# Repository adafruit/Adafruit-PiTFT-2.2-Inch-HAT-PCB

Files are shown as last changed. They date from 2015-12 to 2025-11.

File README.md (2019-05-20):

## Adafruit PiTFT 2.2 Inch LCD Display HAT
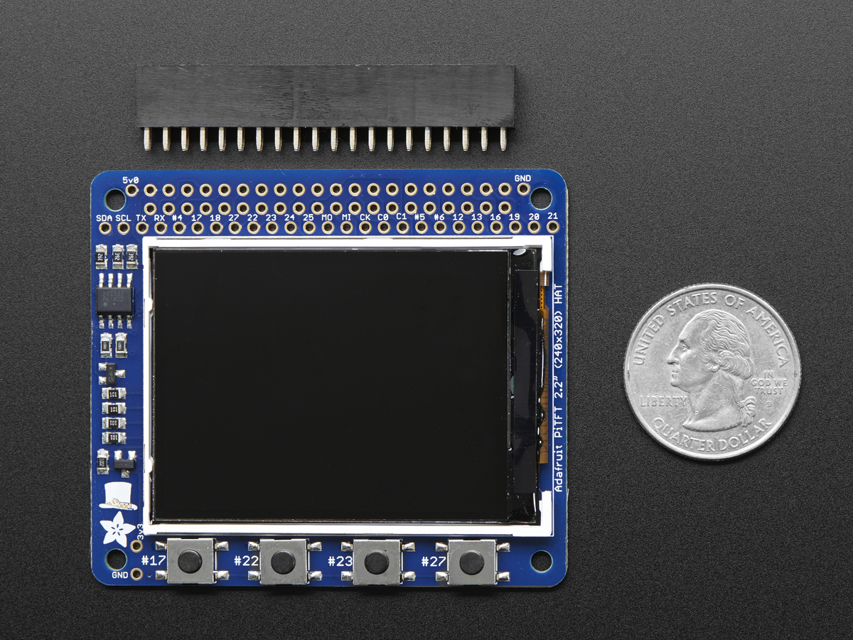
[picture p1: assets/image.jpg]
<a href="http://www.adafruit.com/products/2315"><br/>
Click here to purchase one from the Adafruit shop</a>

The cute PiTFT got even more adorable with this little primary display for Raspberry Pi in HAT form! It features a 2.2" display with 320x240 16-bit color pixels. The HAT uses the high speed SPI interface on the Pi and can use the mini display as a console, X window port, displaying images or video etc. Best of all it plugs right in on top of your Model A+ or B+ and fits into our case quite nicely.

It's designed to plug directly onto the Raspberry Pi 2, Pi 3, Pi Zero or Raspberry Pi 1 Model A+ or B+ . While not specifically designed for Pi Model A or B, you can use it with A/B if you solder in an extra-tall 2x13 header (not included) instead of the included 2x20 header

This design uses the hardware SPI pins (SCK, MOSI, MISO, CE0, CE1) as well as GPIO #25. All other GPIO are unused and are available on a 25-pin long breakout line. Since we had a tiny bit of space, there's 4 flat tactile switches wired to four GPIOs, that you can use if you want to make a basic user interface. For example, you can use one as a power on/off button.

Comes as a fully assembled display PCB and an additional 2x20 GPIO header. Some light soldering is required to attach the 2x20 GPIO header to the HAT but it's fast and easy for anyone with a soldering iron and solder.

PCB files for Adafruit PiTFT 2.2" HAT. The format is EagleCAD schematic and board layout
- https://www.adafruit.com/product/2315

### License

Adafruit invests time and resources providing this open source design, please support Adafruit and open-source hardware by purchasing products from [Adafruit](https://www.adafruit.com)!

All text above must be included in any redistribution

Designed by Limor Fried/Ladyada for Adafruit Industries.
Creative Commons Attribution/Share-Alike, all text above must be included in any redistribution. 
See license.txt for additional information.

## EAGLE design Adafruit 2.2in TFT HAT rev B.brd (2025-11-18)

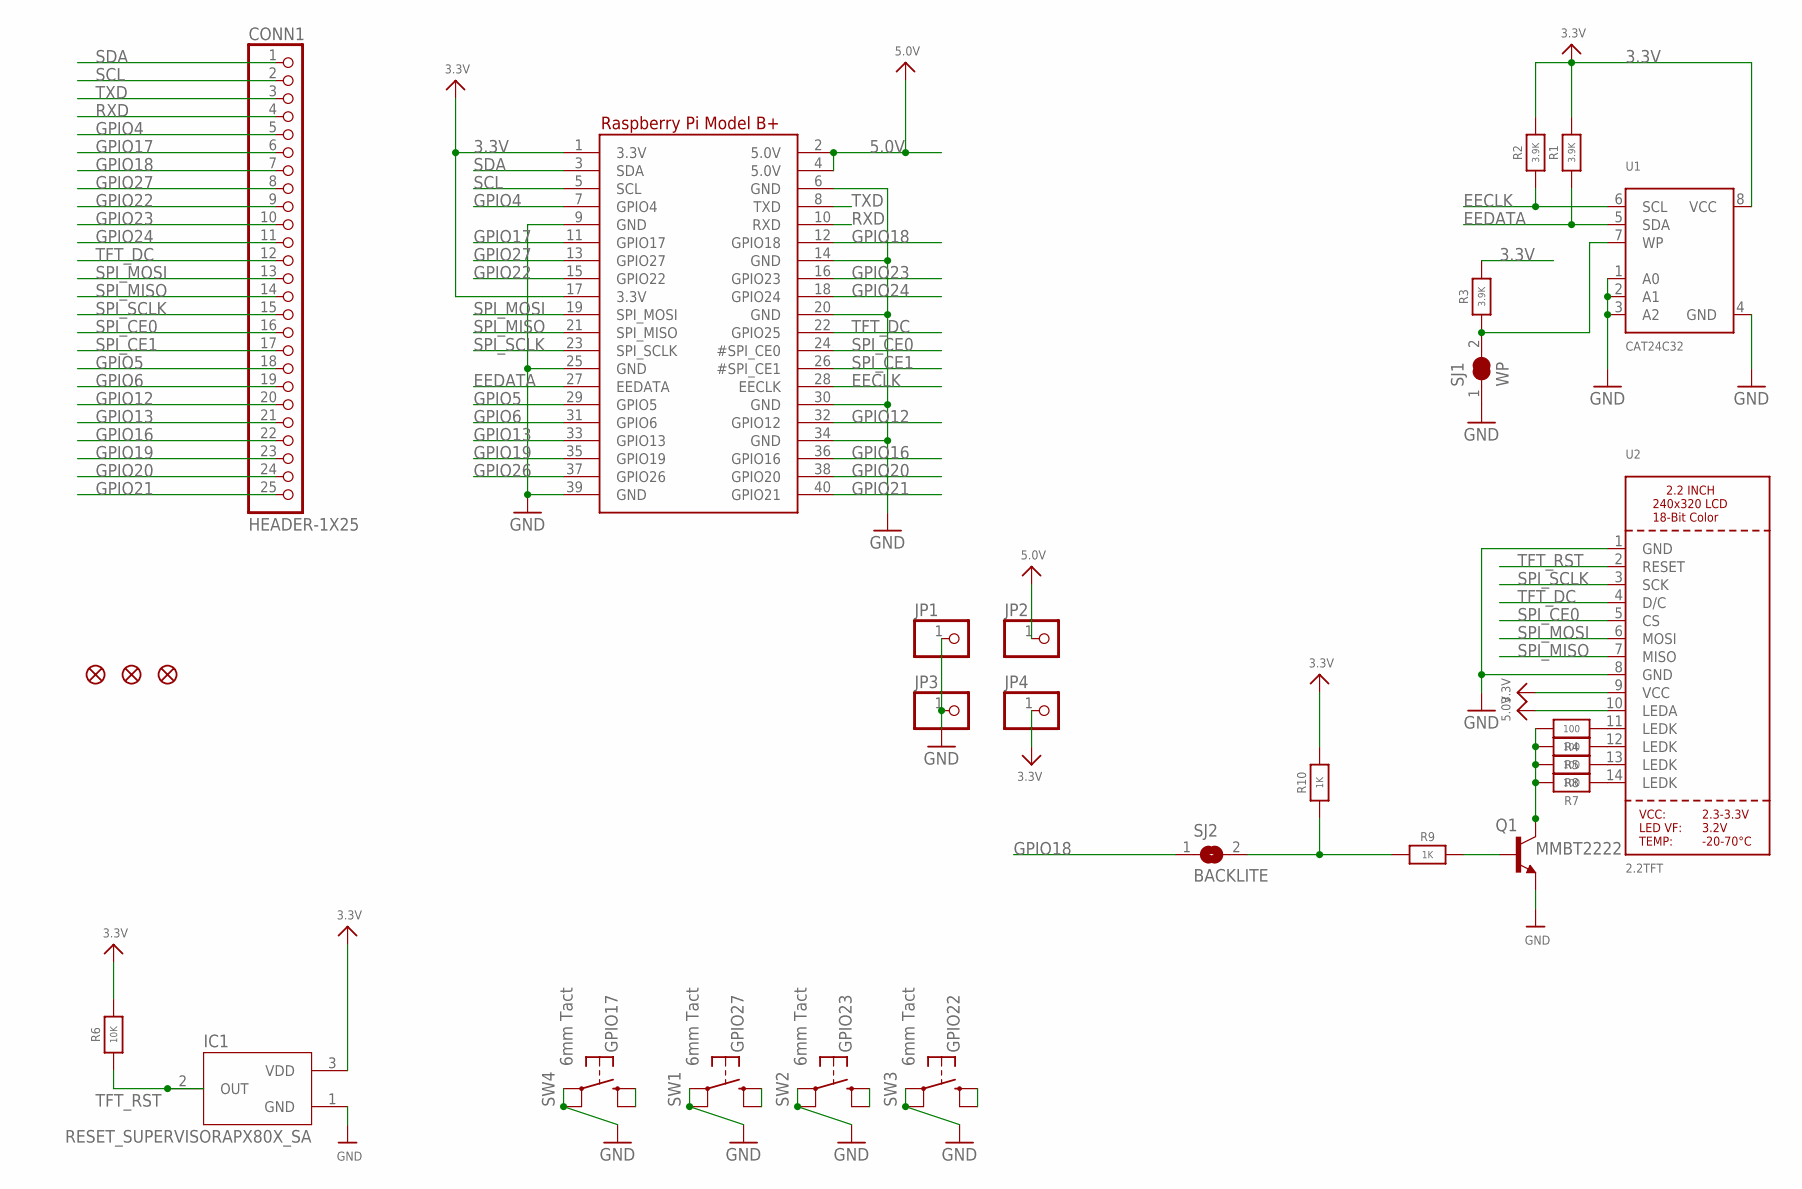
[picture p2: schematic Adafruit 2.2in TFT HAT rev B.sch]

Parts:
CONN1: HEADER-1X25; 1X25_ROUND_70MIL
FID1, FID2, FID3: FIDUCIAL_1MM
IC1: RESET_SUPERVISORAPX80X_SA; SOT23-WIDE
JP1, JP2, JP3, JP4: HEADER-1X1ROUND; 1X01_ROUND
Q1: MMBT2222; SOT23-BEC
R1, R2, R3: 3.9K; 0805-NO
R4, R5, R7, R8: 100; 0805-NO
R6: 10K; 0805-NO
R9, R10: 1K; 0805-NO
RPI1: RASPBERRYPI_BPLUS_HATNODIM; PI_HAT_NODIM
SJ1: WP; SOLDERJUMPER_CLOSEDWIRE
SJ2: BACKLITE; SOLDERJUMPER_CLOSEDWIRE
SW1, SW2, SW3, SW4: 6mm Tact; EVQ-Q2
U1: CAT24C32; SOIC8_150MIL
U2: 2.2TFT; TM022HDH26_2.2IN_LCD

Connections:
3.3V: IC1.3 (VDD), JP4.1, R1.2, R2.2, R3.2, R6.2, R10.2, RPI1.1 (3.3V), RPI1.17 (3.3V), U1.8 (VCC), U2.9 (VCC)
5.0V: JP2.1, RPI1.2 (5.0V), RPI1.4 (5.0V), U2.10 (LEDA)
EECLK: R2.1, RPI1.28 (EECLK), U1.6 (SCL)
EEDATA: R1.1, RPI1.27 (EEDATA), U1.5 (SDA)
GND: IC1.1 (GND), JP1.1, JP3.1, Q1.E, RPI1.6 (GND), RPI1.9 (GND), RPI1.14 (GND), RPI1.20 (GND), RPI1.25 (GND), RPI1.30 (GND), RPI1.34 (GND), RPI1.39 (GND), SJ1.1, SW1.A, SW1.A' (P1), SW2.A, SW2.A' (P1), SW3.A, SW3.A' (P1), SW4.A, SW4.A' (P1), U1.1 (A0), U1.2 (A1), U1.3 (A2), U1.4 (GND), U2.1 (GND), U2.8 (GND)
GPIO4: CONN1.5, RPI1.7 (GPIO4)
GPIO5: CONN1.18, RPI1.29 (GPIO5)
GPIO6: CONN1.19, RPI1.31 (GPIO6)
GPIO12: CONN1.20, RPI1.32 (GPIO12)
GPIO13: CONN1.21, RPI1.33 (GPIO13)
GPIO16: CONN1.22, RPI1.36 (GPIO16)
GPIO17: CONN1.6, RPI1.11 (GPIO17), SW4.B (S), SW4.B' (S1)
GPIO18: CONN1.7, RPI1.12 (GPIO18), SJ2.1
GPIO19: CONN1.23, RPI1.35 (GPIO19)
GPIO20: CONN1.24, RPI1.38 (GPIO20)
GPIO21: CONN1.25, RPI1.40 (GPIO21)
GPIO22: CONN1.9, RPI1.15 (GPIO22), SW3.B (S), SW3.B' (S1)
GPIO23: CONN1.10, RPI1.16 (GPIO23), SW2.B (S), SW2.B' (S1)
GPIO24: CONN1.11, RPI1.18 (GPIO24)
GPIO26: RPI1.37 (GPIO26)
GPIO27: CONN1.8, RPI1.13 (GPIO27), SW1.B (S), SW1.B' (S1)
unnamed: R4.1, U2.11 (LEDK)
unnamed: R5.1, U2.12 (LEDK)
unnamed: R7.1, U2.14 (LEDK)
unnamed: R8.1, U2.13 (LEDK)
unnamed: Q1.C, R4.2, R5.2, R7.2, R8.2
unnamed: Q1.B, R9.2
unnamed: R9.1, R10.1, SJ2.2
unnamed: R3.1, SJ1.2, U1.7 (WP)
RXD: CONN1.4, RPI1.10 (RXD)
SCL: CONN1.2, RPI1.5 (SCL)
SDA: CONN1.1, RPI1.3 (SDA)
SPI_CE0: CONN1.16, RPI1.24 (#SPI_CE0), U2.5 (CS)
SPI_CE1: CONN1.17, RPI1.26 (#SPI_CE1)
SPI_MISO: CONN1.14, RPI1.21 (SPI_MISO), U2.7 (MISO)
SPI_MOSI: CONN1.13, RPI1.19 (SPI_MOSI), U2.6 (MOSI)
SPI_SCLK: CONN1.15, RPI1.23 (SPI_SCLK), U2.3 (SCK)
TFT_DC: CONN1.12, RPI1.22 (GPIO25), U2.4 (D/C)
TFT_RST: IC1.2 (OUT), R6.1, U2.2 (RESET)
TXD: CONN1.3, RPI1.8 (TXD)

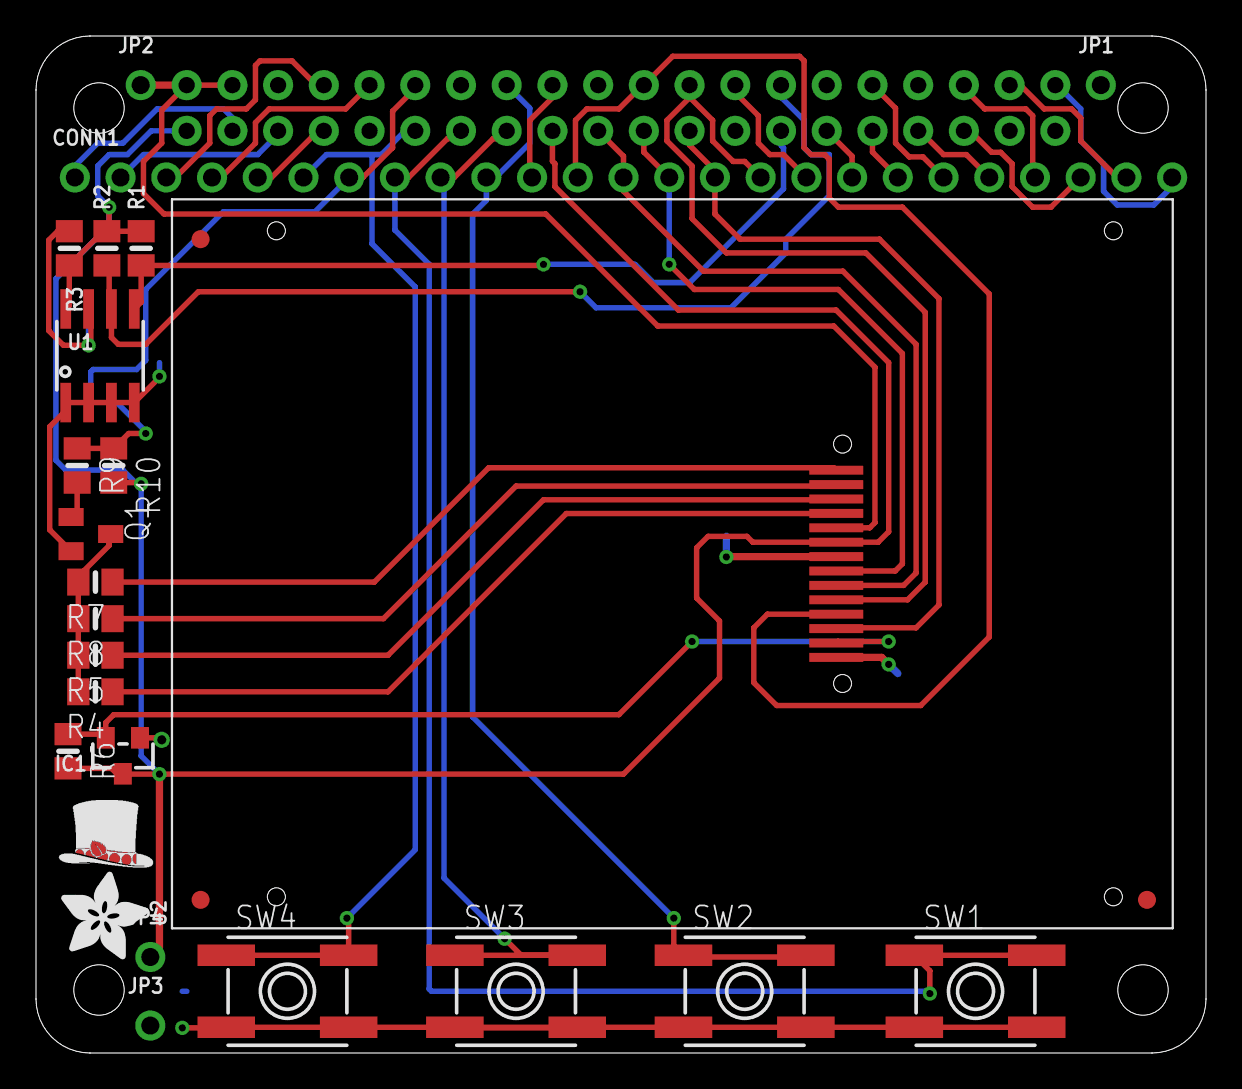
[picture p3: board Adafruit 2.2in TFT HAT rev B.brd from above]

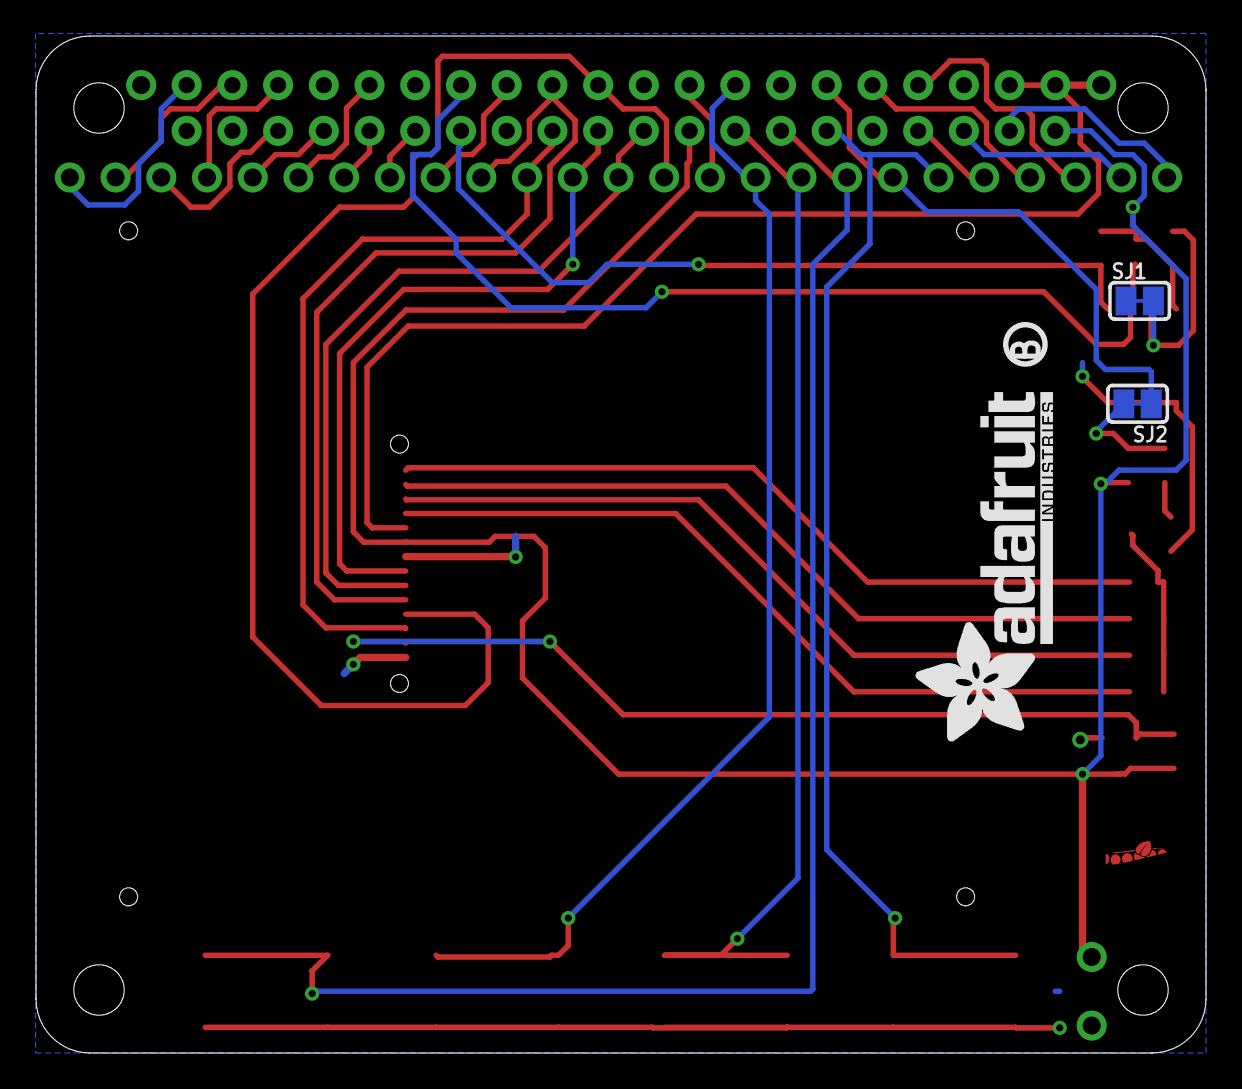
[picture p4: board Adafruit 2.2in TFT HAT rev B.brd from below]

Board: 2 copper layers, 65.0 x 56.5 mm, 69 parts (6 on the bottom side), 39 nets.

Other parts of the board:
PLABEL0: PLABEL0
PLABEL1: PLABEL1
PLABEL2: PLABEL2
PLABEL3: PLABEL3
PLABEL4: PLABEL4
PLABEL5: PLABEL5
PLABEL6: PLABEL6
PLABEL7: PLABEL7
PLABEL8: PLABEL8
PLABEL9: PLABEL9
PLABEL10: PLABEL10
PLABEL11: PLABEL11
PLABEL12: PLABEL12
PLABEL13: PLABEL13
PLABEL14: PLABEL14
PLABEL15: PLABEL15
PLABEL16: PLABEL16
PLABEL17: PLABEL17
PLABEL18: PLABEL18
PLABEL19: PLABEL19
PLABEL20: PLABEL20
PLABEL21: PLABEL21
PLABEL22: PLABEL22
PLABEL23: PLABEL23
PLABEL24: PLABEL24
PLABEL25: PLABEL25
PLABEL26: PLABEL26
PLABEL27: PLABEL27
PLABEL28: PLABEL28
PLABEL29: PLABEL29
PLABEL30: PLABEL30
PLABEL31: PLABEL31
PLABEL32: PLABEL32
PLABEL33: PLABEL33
PLABEL34: PLABEL34
PLABEL35: PLABEL35
U$1: ADAFRUIT_5MM
U$3: ADAFRUIT_TEXT_20MM
U$4: PIHATLOGO
U$12: PCBFEAT-REV-056

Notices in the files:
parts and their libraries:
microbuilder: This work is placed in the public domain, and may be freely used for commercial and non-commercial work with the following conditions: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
